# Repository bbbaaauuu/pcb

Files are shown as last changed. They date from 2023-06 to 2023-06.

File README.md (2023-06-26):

# pcb

PCB joyskick for radio controlled bot based on Arduino 



Work plan:
- [ ] Add and connect all components in EasyEDA (schematic mode)
- [ ] Convert to PCB mode
- [ ] Autotrace and correct traces (if necessary)
- [ ] Export .dxf to Rhino7 and draw vectors (holes diameter 1 mm, trace width 1 mm)
- [ ] Mirror PCB
- [ ] ArtCAM .gcode
- [ ] Milling traces and holes
- [ ] Removing the copper layer completely from the opposite side
- [ ] Add design

Components used:
- Arduino Pro Micro
- NRF+
- Joystick

Schematics:



PCB view:



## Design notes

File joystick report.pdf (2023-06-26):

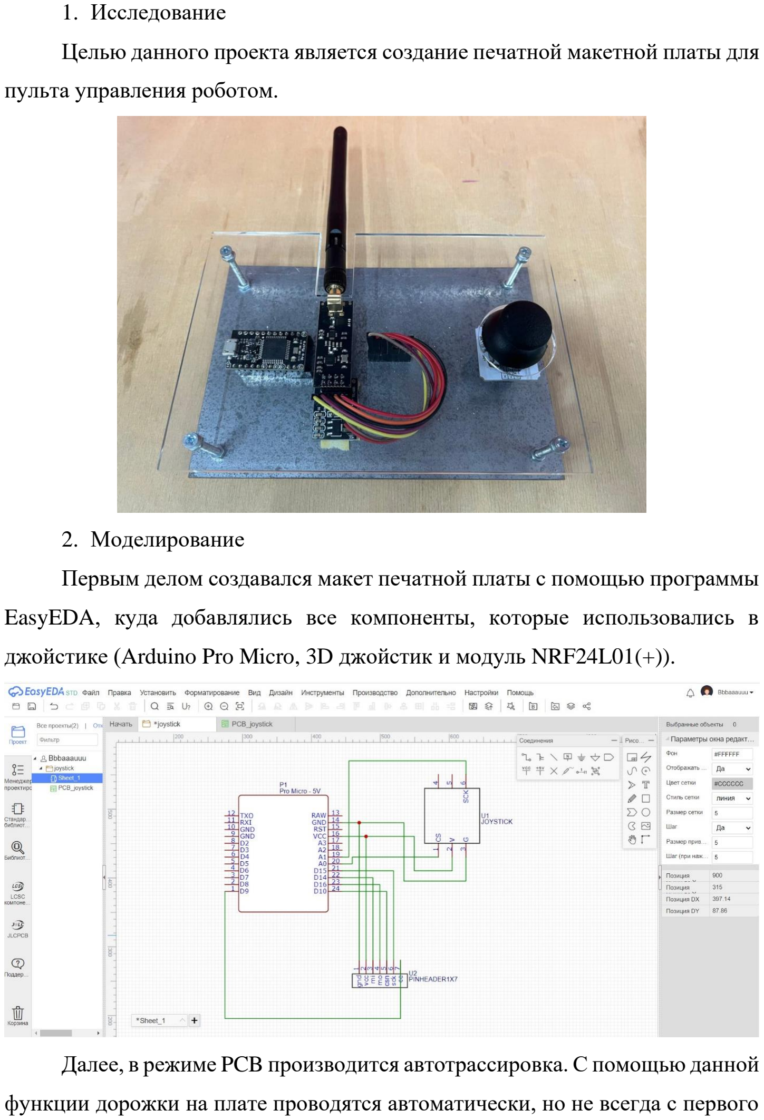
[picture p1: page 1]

1. Исследование

Целью данного проекта является создание печатной макетной платы для

пульта управления роботом.

2. Моделирование

Первым делом создавался макет печатной платы с помощью программы

EasyEDA, куда добавлялись все компоненты, которые использовались в

джойстике (Arduino Pro Micro, 3D джойстик и модуль NRF24L01(+)).

Далее, в режиме PCB производится автотрассировка. С помощью данной

функции дорожки на плате проводятся автоматически, но не всегда с первого раза, поэтому необходимо вручную двигать как сами дорожки, так и

компоненты.

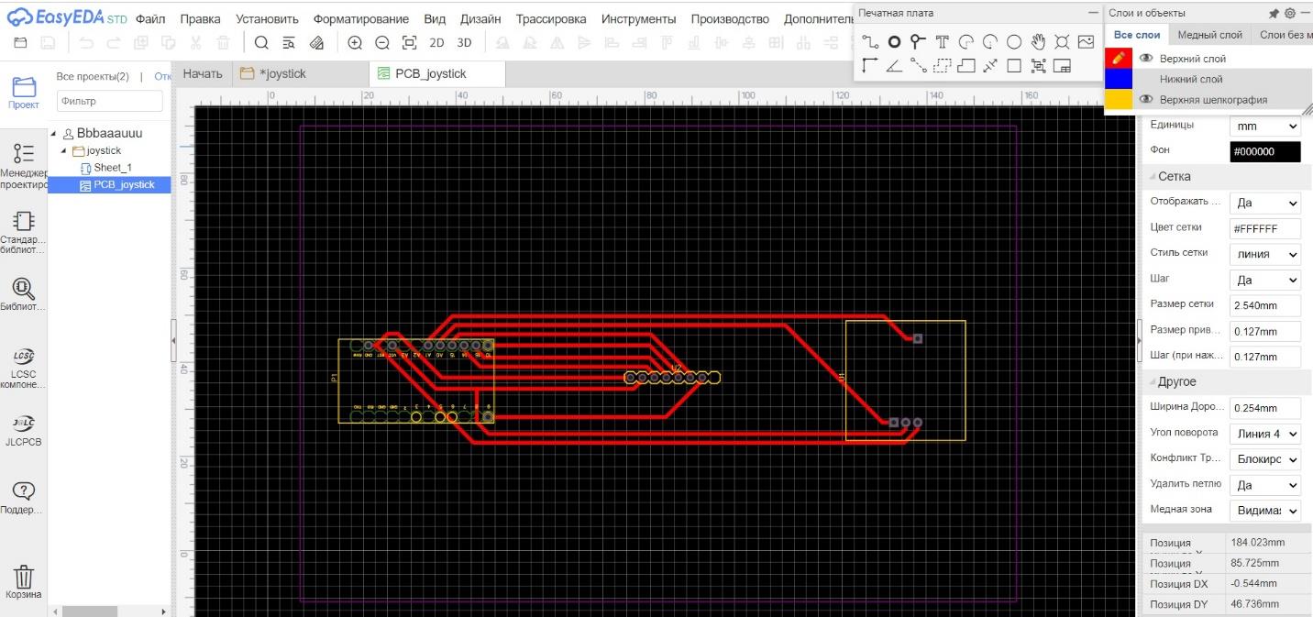
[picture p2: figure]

Далее, файл в формате .dxf загружается в одну из CAD программ, где

настраивается ширина дорожек. В данной работе использовалась программа

Rhino 7, где с помощью Grasshopper производился offset curves.

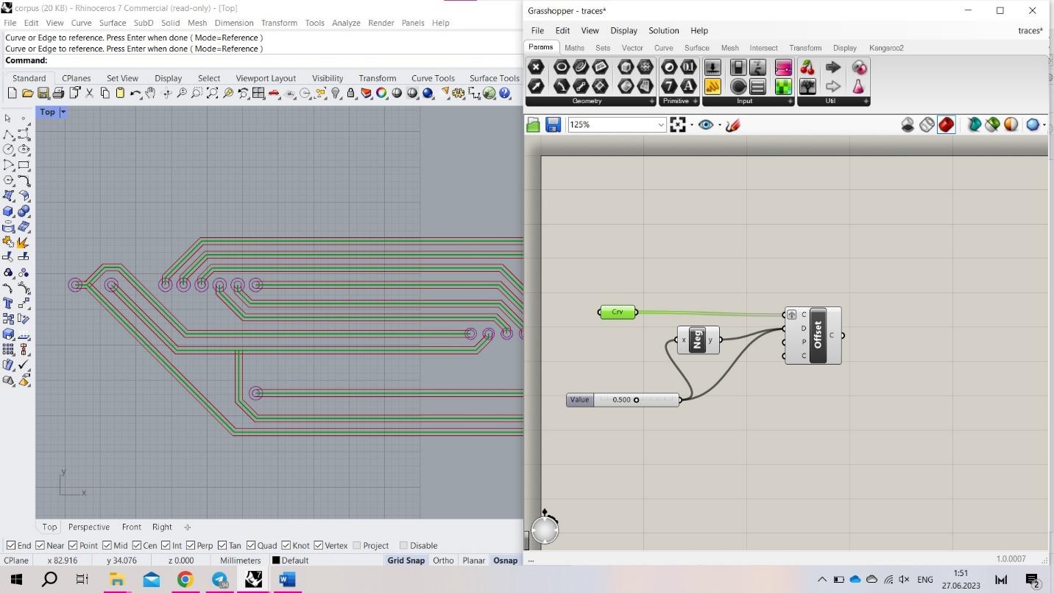
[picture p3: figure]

В программе ArtCAM устанавливаются траектории для фрезеровки

платы, однако перед этим необходимо откорректировать векторы в CorelDraw.

После этого настраиваются 2 отдельные траектории для дорожек и для

отверстий, так как они фрезеруются разными инструментами.

Также перед фрезеровкой необходимо горизонтально отзеркалить все

векторы, потому что ножки пинхэдов будут припаиваться с обратной стороны

платы. Это делается для того, чтобы не припаивать компоненты напрямую.

Они будут съемными.

Корпус для джойстика также был смоделирован в Rhino 7 для

дальнейшего вырезания из акрила на лазере.

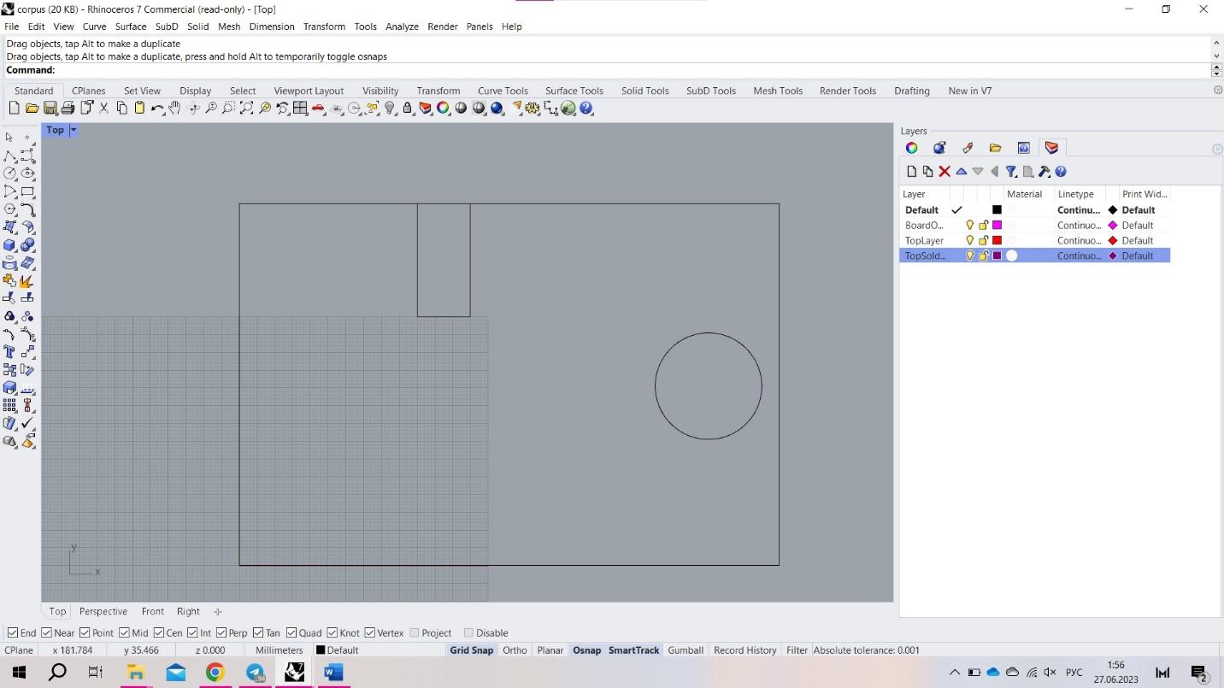
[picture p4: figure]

3. Fabrication

Плата вырезалась на фрезерном станке Roland Modela MDX 540 с

использованием трех инструментов. Первый (end mill 0.8 mm) – для отверстий,

второй (V-bit 20/45 deg) – для дорожек, третий (end mill 6 mm) – для снятия

медного слоя с обратной стороны платы.

На лазерном станке Trotec вырезался корпус для пульта из прозрачного

акрила с отверстиями для антенны радиомодуля и джойстика.

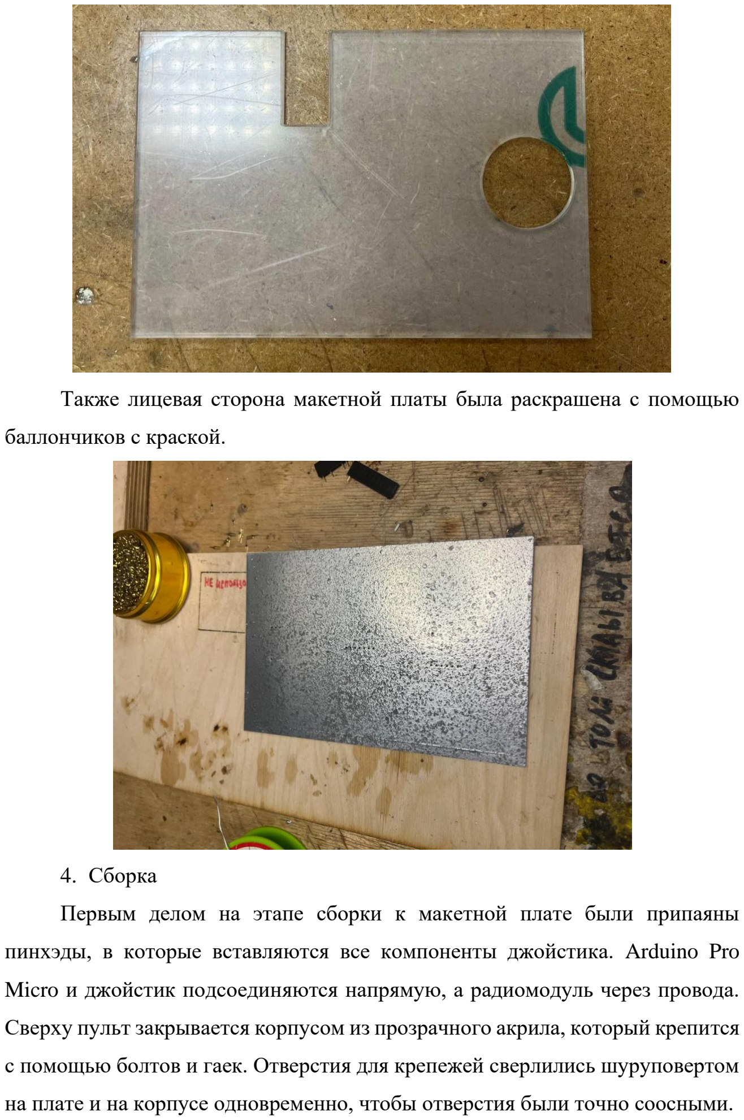
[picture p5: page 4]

Также лицевая сторона макетной платы была раскрашена с помощью

баллончиков с краской.

4. Сборка

Первым делом на этапе сборки к макетной плате были припаяны

пинхэды, в которые вставляются все компоненты джойстика. Arduino Pro

Micro и джойстик подсоединяются напрямую, а радиомодуль через провода.

Сверху пульт закрывается корпусом из прозрачного акрила, который крепится

с помощью болтов и гаек. Отверстия для крепежей сверлились шуруповертом

на плате и на корпусе одновременно, чтобы отверстия были точно соосными.

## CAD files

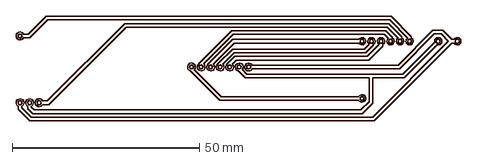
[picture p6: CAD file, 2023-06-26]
CAD/pcb.dxf
118.6 x 27.9 mm

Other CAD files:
CAD/corpus.3dm
